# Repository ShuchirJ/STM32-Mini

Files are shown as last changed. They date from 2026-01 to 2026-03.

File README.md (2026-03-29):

# STM32 Mini
A small, stm32f072 devboard in the pico form factor! I've played around with the RP2040 and various ESP32 chips for the past few years, but I wanted to try something different. The STM32 series of microcontrollers are very popular especially for low power usage, and I wanted to try using one myself. There's also less abstraction (imo-at least compared to MicroPython) when writing code for the STM32 and I think it'd be a great chance for me to practice my rust a little. 

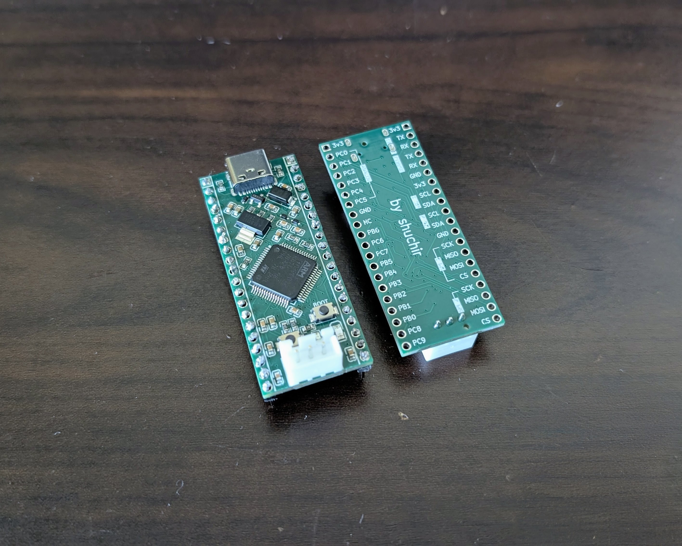
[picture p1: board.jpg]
board

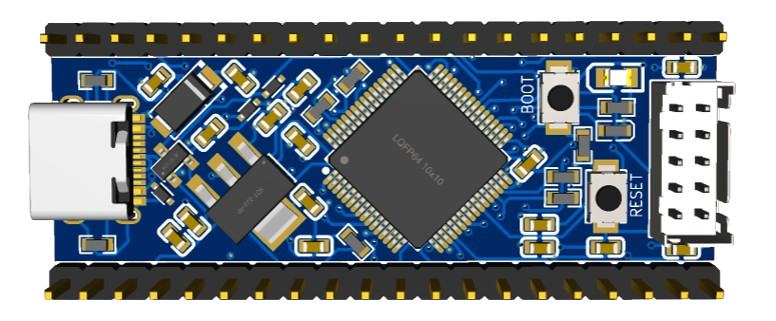
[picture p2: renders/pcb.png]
render


## Usage
1. Clone and open the firmware/ folder (or clone the firmware repo directly: [ShuchirJ/stm32-blinky](https://github.com/ShuchirJ/stm32-blinky))
2. Install the Rust toolchain and the thumbv6m-none-eabi target (`rustup target add thumbv6m-none-eabi`) 
> [!NOTE]
> This step assumes you are connected via SWD debugger. If you want to flash the firmware using USB, install [rs-dfu](https://github.com/EdgeTX/rs-dfu) (or similar) and skip to step 4.
3. Build and flash the firmware using `cargo run --release`

Flashing via DFU: 

4. `cargo build --release`
5. `cargo objcopy --release --bin stm32-blinky -- -O binary target/thumbv6m-none-eabi/release/stm32-blinky.bin`
6. `rdfu write --start-address 0x08000000 target/thumbv6m-none-eabi/release/stm32-blinky.bin` (or similar command for an alternative dfu utility)

schematic

## Stackup
The board follows a SIG-GND-PWR-SIG stackup.

SIG (1):
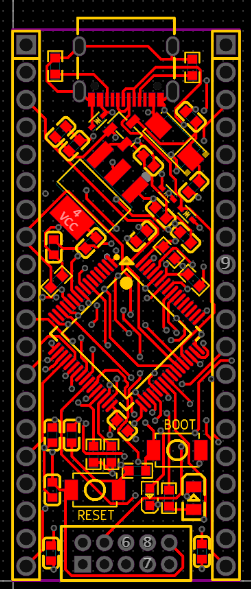
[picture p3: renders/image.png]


GND (2):
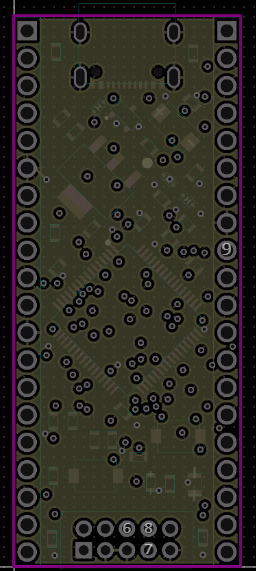
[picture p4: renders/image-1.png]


PWR (3):
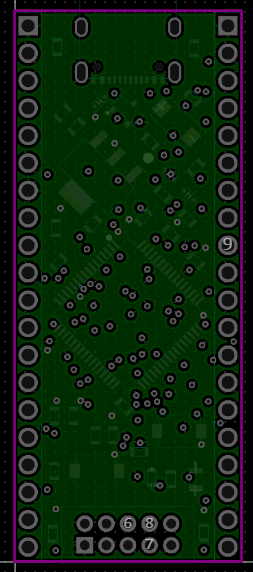
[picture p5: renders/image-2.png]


SIG (4):
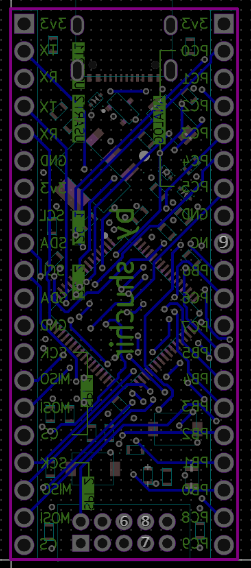
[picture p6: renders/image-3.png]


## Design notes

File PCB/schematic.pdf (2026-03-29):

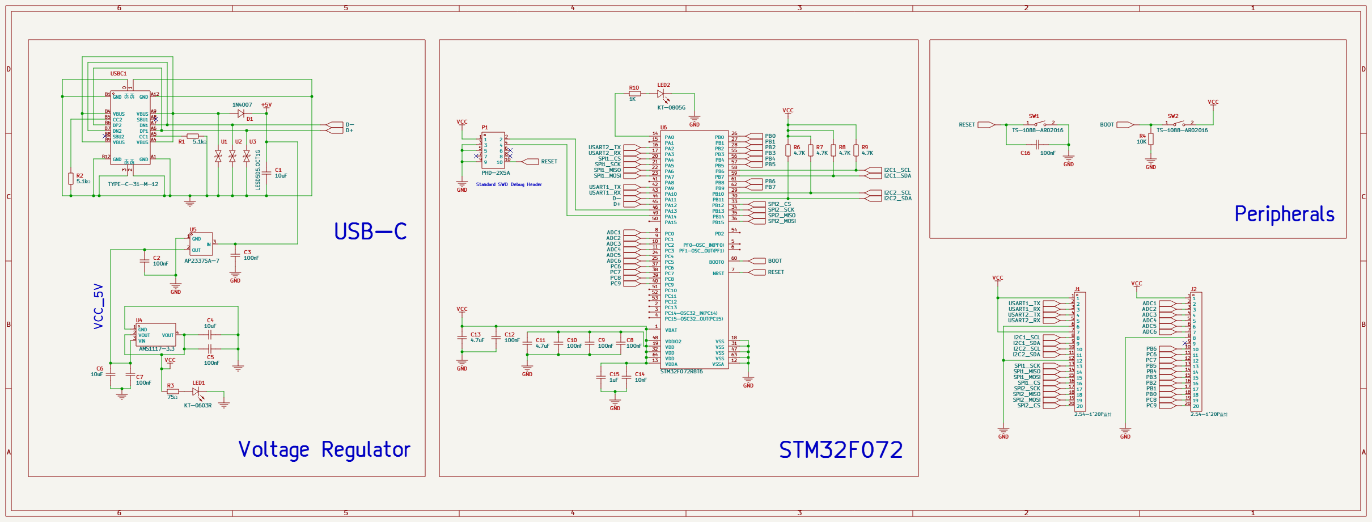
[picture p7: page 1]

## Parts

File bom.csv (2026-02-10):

Quantity | Comment | Value | Manufacturer Part | Manufacturer | Supplier Part | Supplier | Price | Link
1 | 1k? | 1k? | 0603WAF1001T5E | UNI-ROYAL(??) | C21190 | LCSC | 0.0002
1 | 1N4007 |  | 1N4007 | TWGMC(??) | C727081 | LCSC | 0.0013
1 | 1uF | 1uF | CL10A105KB8NNNC | SAMSUNG(??) | C15849 | LCSC | 0.0009
1 | 10k? | 10k? | 0603WAF1002T5E | UNI-ROYAL(??) | C25804 | LCSC | 0.0002
1 | 10nF | 10nF | 0603B103K500NT | FH(??) | C57112 | LCSC | 0.0005
1 | 75? | 75? | 0603WAF750JT5E | UNI-ROYAL(??) | C4275 | LCSC | 0.0002
1 | AMS1117-3.3 |  | AMS1117-3.3 | AMS | C6186 | LCSC | 0.0286
1 | AP2337SA-7 |  | AP2337SA-7 | DIODES(??) | C150497 | LCSC | 0.0215
1 | KT-0603R |  | KT-0603R | KENTO | C2286 | LCSC | 0.001
1 | KT-0805G |  | KT-0805G | KENTO | C2297 | LCSC | 0.0023
1 | PHD-2X5A |  | PHD-2X5A | BOOMELE(????) | C49123 | LCSC | 0.0066
1 | STM32F072R8T6 |  | STM32F072R8T6 | ST(?????) | C87900 | LCSC | 0.2764
1 | TYPE-C-31-M-12 |  | TYPE-C-31-M-12 | ???? | C165948 | LCSC | 0.0266
2 | 2.54-1*20P?? |  | 2.54-1*20P?? | BOOMELE(????) | C50981 | LCSC | 0.0177
2 | 4.7uF | 4.7uF | CL10A475KO8NNNC | SAMSUNG(??) | C19666 | LCSC | 0.0015
2 | 5.1k? | 5.1k? | 0603WAF5101T5E | UNI-ROYAL(??) | C23186 | LCSC | 0.0002
2 | TS-1088-AR02016 |  | TS-1088-AR02016 | XUNPU(??) | C720477 | LCSC | 0.007
3 | 10uF | 10uF | CL10A106KP8NNNC | SAMSUNG(??) | C19702 | LCSC | 0.001
3 | LESD5D5.0CT1G |  | LESD5D5.0CT1G | Leiditech(????) | C5246195 | LCSC | 0.0058
4 | 4.7k? | 4.7k? | 0603WAF4701T5E | UNI-ROYAL(??) | C23162 | LCSC | 0.0002
9 | 100nF | 100nF | CC0603KRX7R9BB104 | YAGEO(??) | C14663 | LCSC | 0.0004
1 | 20PCS 1x20 20PIN Single Row Straight Male Pin Header Connector 2.54MM |  |  |  |  | AliExpress | 2.57 | https://www.aliexpress.us/item/2255800867206912.html
 |  |  |  |  |  | Total | 3.014

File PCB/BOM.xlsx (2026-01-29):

No. | Quantity | Comment | Value | Manufacturer Part | Manufacturer | Supplier Part | Supplier
1 | 1 | 1K | 1K
2 | 1 | 1N4007 |  | 1N4007 | TWGMC(迪嘉) | C727081 | LCSC
3 | 1 | 1uF | 1uF
4 | 1 | 2.54-1*20P直针 |  | 2.54-1*20P直针 | BOOMELE(博穆精密) | C50981 | LCSC
5 | 1 | 4.7K | 4.7K
6 | 1 | 4.7uF | 4.7uF | CL10A475KO8NNNC | SAMSUNG(三星) | C19666 | LCSC
7 | 1 | 5.1kΩ | 5.1kΩ | 0603WAF5101T5E | UNI-ROYAL(厚声) | C23186 | LCSC
8 | 1 | 10K | 10K
9 | 1 | 10nF | 10nF | CC0603KRX7R9BB103 | YAGEO(国巨) | C100042 | LCSC
10 | 1 | 10uF | 10uF | CL10A106KP8NNNC | SAMSUNG(三星) | C19702 | LCSC
11 | 1 | 75Ω | 75Ω | 0603WAF750JT5E | UNI-ROYAL(厚声) | C4275 | LCSC
12 | 1 | 100nF | 100nF
13 | 1 | 100nF | 100nF | CC0603KRX7R9BB104 | YAGEO(国巨) | C14663 | LCSC
14 | 1 | AMS1117-3.3 |  | AMS1117-3.3 | AMS | C6186 | LCSC
15 | 1 | AP2337SA-7 |  | AP2337SA-7 | DIODES(美台) | C150497 | LCSC
16 | 1 | KT-0603R |  | KT-0603R | KENTO | C2286 | LCSC
17 | 1 | KT-0805G |  | KT-0805G | KENTO | C2297 | LCSC
18 | 1 | LESD5D5.0CT1G |  | LESD5D5.0CT1G | Leiditech(雷卯电子) | C5246195 | LCSC
19 | 1 | PHD-2X5A |  | PHD-2X5A | BOOMELE(博穆精密) | C49123 | LCSC
20 | 1 | STM32F072R8T6 |  | STM32F072R8T6 | ST(意法半导体) | C87900 | LCSC
21 | 1 | TS-1088-AR02016 |  | TS-1088-AR02016 | XUNPU(讯普) | C720477 | LCSC
22 | 1 | TYPE-C-31-M-12 |  | TYPE-C-31-M-12 | 韩国韩荣 | C165948 | LCSC

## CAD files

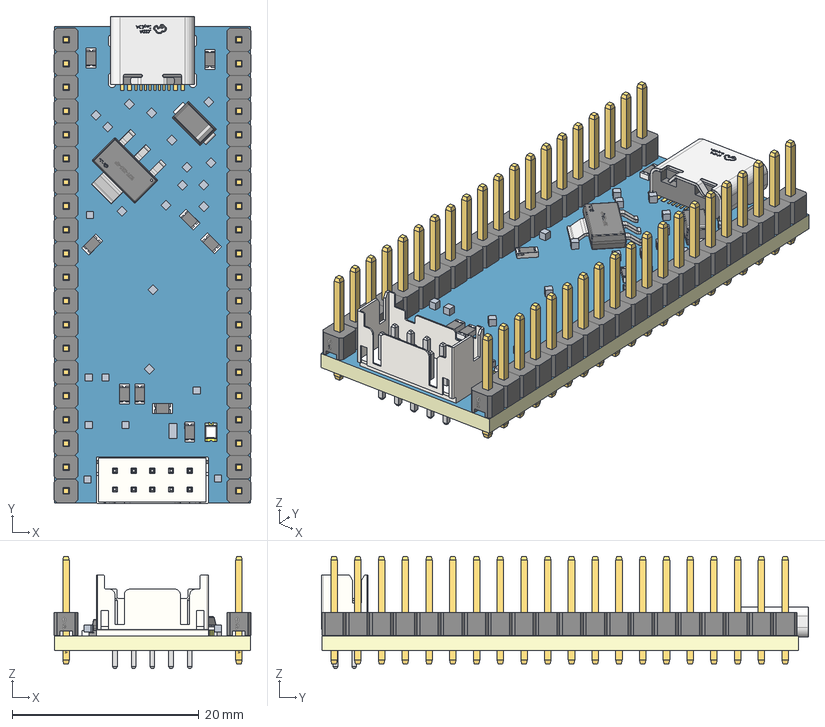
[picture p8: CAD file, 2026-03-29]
3D/3d_model.step
21.0 x 52.1 x 12.0 mm
Board~u6RN
TopCopper~u6RN
BottomCopper~u6RN
TopFpcStiffener~u6RN
BottomFpcStiffener~u6RN
C14~C0603~C0603_L1.6-W0.8-H0.8~u6RN x 16
LED0603-RD~LED0603-RD~u6RN
SW2~SW-SMD_L3.9-W3.0-P4.45~SW-SMD_L3.9-W2.9-H2.0-LS4.8~u6RN x 2
LED0805-R-RD~LED0805-RD~u6RN
SMA_L4.3-W2.5-LS5.0-RD~SMA_L4.3-W2.5-LS5.0-RD~u6RN
R0603~R0603~u6RN x 9
SOT-223-3_L6.5-W3.4-P2.30-LS7.0-BR~SOT-223-4P_ L6.5-W3.5-H1.6-LS7.0-P2.30~u6RN
SOT-23-3_L2.9-W1.3-P1.90-LS2.4-BR~SOT-23-3P_ L2.9-W1.3-H1.0-LS2.4-P0.95~u6RN
LQFP-64_L10.0-W10.0-P0.50-LS12.0-BL~LQFP-64_ L10.0-W10.0-H1.4-LS12.0-P0.50~u6RN
USB-C_SMD-TYPE-C-31-M-12~USB-C_SMD-TYPE-C-31-M-12~u6RN
U3~SOD-523_L1.2-W0.8-LS1.6-BI~SOD-523_L1.2-W0.8-LS1.6-BI~u6RN x 3
HDR-TH_20P-P2.54-V-M-1~HDR-M-2.54_1x20~u6RN x 2
CONN-TH_10P-P2.00_PHD2.0MM-2X5~CONN-TH_10P-P2.00_PHD2.0MM-2X5~u6RN

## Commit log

2026-01-29 initial pcb files
    [BOM.xlsx, PickAndPlace.xlsx]
2026-01-29 add firmware to blink the onboard led
2026-01-30 add readme
    [bom.csv]
2026-02-09 add schematic, photos
2026-03-29 update repo structure
    [3d_model.step, BOM.xlsx, PickAndPlace.xlsx]
